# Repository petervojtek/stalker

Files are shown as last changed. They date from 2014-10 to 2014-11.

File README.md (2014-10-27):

Stalker
=======

_"The Zone wants to be respected. Otherwise it will punish."_ &mdash;  [ Stalker, 1979](http://en.wikipedia.org/wiki/Stalker_(1979_film))

Arduino&ndash;based door stalking device.

```
2014-10-03 11:30 door status changed to OPEN 
2014-10-03 11:32 door status changed to CLOSED
```

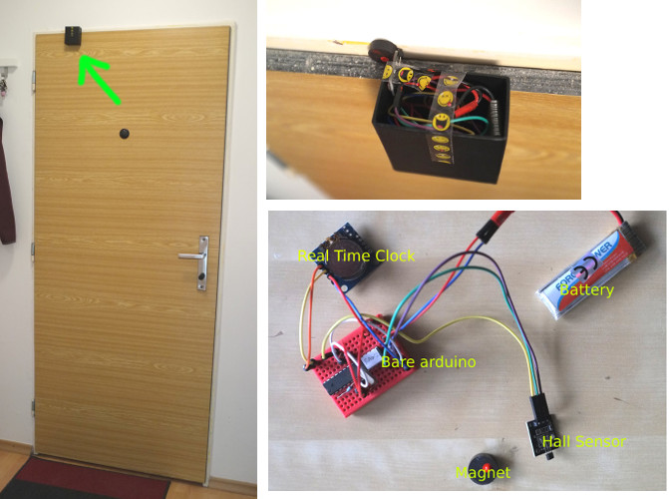
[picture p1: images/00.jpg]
Stalker


Features
--------

* Battery powered: will run for 3 months from `600mAh` lion battery.
* Cheap (20 USD): so that you can attach it to public-space door
* Hall sensor (magnet) based door status detection 
* Log entries are persistently stored to 32kB EEPROM on RTC board (6400 entries)

Wiring & Code
-------------

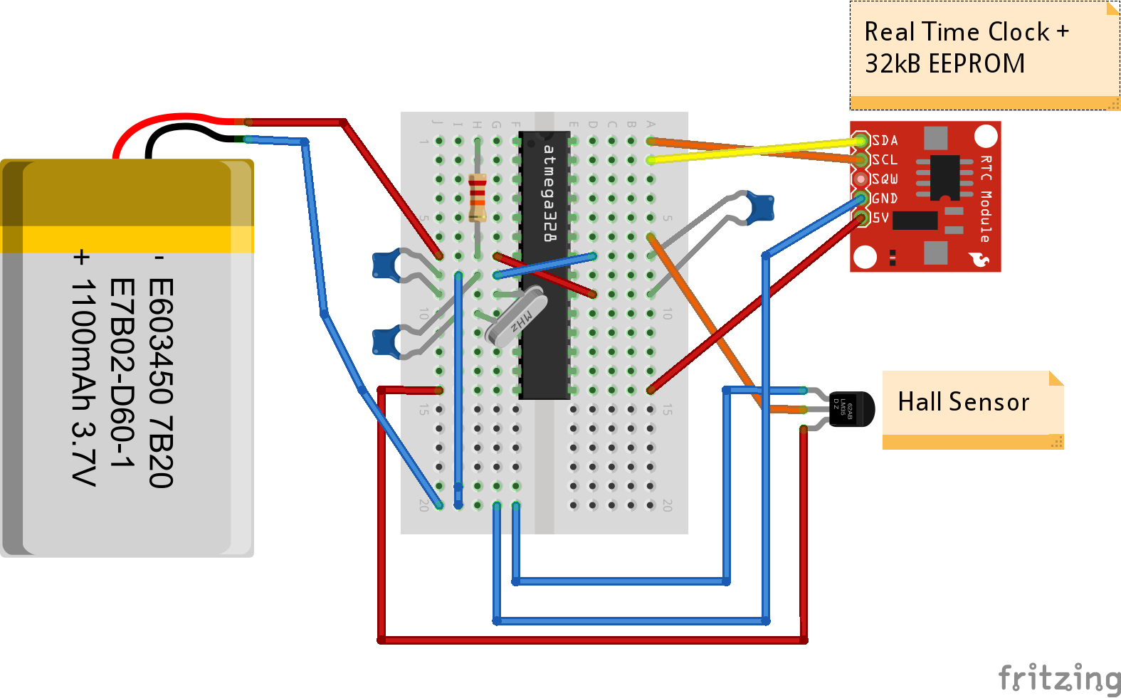
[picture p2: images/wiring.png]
Stalker fritzing diagram


Few notes on the [arduino source code](https://github.com/petervojtek/stalker/blob/master/stalker.ino):
* The circuit and source code is optimized to maximize battery life.
* Bare arduino is powered directly from lion battery without any voltage regulation. 
* Hall sensor is powered from arduino's digital pin (and not directly from battery) to cut its power consumption as much as possible. 
 * Similarly, real time clock is powered from arduino's digital pin for the same purpose.
* [LowPower.h](https://github.com/rocketscream/Low-Power) sleep mode is used as much as possible.
* Records are stored into A24C32 EEPROM (32kB), which is located on the RTC board.
* Use `printHistory()` function to get door logs from EEPROM.

Assembly
--------

You have to attach the Stalker and magnet on a door so that:
* the magnet is near the hall sensor when door is closed
* distance between magnet and hall sensor increase as door opens

The [KY-003 Hall sensor](http://www.ebay.com/itm/KY-003-Hall-Magnetic-Sensor-Module-for-Arduino-AVR-PIC-Good-/370886143225) has a LED which blinks when magnet is near, which is useful for tuning the hall sensor-to-magnet position.

Battery Life
------------

* If you want to achieve good battery life (months), you cannot use regular arduino which is too greedy in terms of current consumption. Instead [use bare atmega328 chip with arduino bootloader](https://github.com/petervojtek/diy/wiki/Arduino-with-Very-Low-Power-Consumption).
* Current draw is `0.20mA` when Stalker is on low-power sleep. 
* Every 2 seconds there is higher power demand as the hall sensor wakes up for 15 milliseconds and measures door status.
 * Only when hall sensor detects door status change, real time clock circuit is powered on and current time is fetched.
* I assume the average current draw is not more than `0.25mA` (unfortunately it is not possible to measure the current draw peaks properly with simple multimeter).
* `600mAh battery / 0.25 mA = 2400 hours = 100 days`

Bill of Material
----------------

Prices below include shipping to EU.

* [Atmega328 bare Arduino Uno Kit](http://www.ebay.de/itm/ATMEGA328-PU-ARDUINO-UNO-KIT-mit-5V-Spannungsstabilisator-MCU-A449-/261357577770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): 7.3 Euro
 * [mini breadboard](http://www.ebay.com/itm/Mini-Nickel-Plating-Breadboard-170-Tie-points-for-Arduino-Shield-Black-TN2F-/281265100067): 0.7 Euro
 * few wires 
* [KY-003 Hall sensor](http://www.ebay.com/itm/KY-003-Hall-Magnetic-Sensor-Module-for-Arduino-AVR-PIC-Good-/370886143225): 1.74 Euro
* [I2C Real Time Clock](http://www.ebay.com/itm/Arduino-I2C-RTC-DS1307-AT24C32-Real-Time-Clock-Module-For-AVR-ARM-PIC-SMD-/170910326110): 0.88 Euro
 * [CR2302 battery](http://www.ebay.com/itm/5-x-CR2032-DL2032-ECR2032-5004LC-3-Volt-Button-Cell-Battery-SL-/291197049625) ~ 0.2 Euro
* [600mAh lion battery](http://www.ebay.ca/itm/3-7V-600mAh-Lipo-Battery-for-Walkera-Syma-WLtoys-V929-V949-V959-V212-V222-/380960159510): 4.8 Euro
* Magnet
* Enclosure

Sum: 15.6 Euro (~ 19.52 USD)

TODOs
-----

* Add bluetooth module to wireless export door status records into a nearby cellphone.
* The current data format used to log door record into EEPROM is not effective - one log entry occupies 5 bytes, can be optimized to 3 bytes.
* There is no EEPROM memory overflow safety.

If you would like to contribute to Stalker's source code, you are welcome to share your enhancements via pull request.

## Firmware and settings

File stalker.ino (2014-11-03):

#include <EEPROM.h>
#include <lowpower.h>

// set to true to debug and see history of door open/close logs
// set to false in production mode
#define WITH_SERIAL_OUTPUT false 

// RTC parts of code are based on http://www.instructables.com/id/Setting-the-DS1307-Real-Time-Clock-using-the-Seria/
// which means this source code is licensed under Attribution-NonCommercial-ShareAlike

#include <Wire.h>
#define RTC_DIGITAL_POWER_PIN 9 // we turn off the rtc board between measurements to save battery
const int DS1307 = 0x68; // i2c Address of DS1307 from data sheets
const int EEPROM_AT24C32 = 0x50; // i2c address of 32kB eeprom, located on the same rtc board

byte second = 0;
byte minute = 0;
byte hour = 0;
byte weekday = 0;
byte monthday = 0;
byte month = 0;
byte year = 14; // fixed, we do not expect to run more than one year from battery

// door status
#define HALL_SENSOR_ANALOG_READ_PIN 0 
#define DOOR_OPEN 0
#define DOOR_CLOSED 1
#define HALL_SENSOR_DIGITAL_POWER_PIN 8 // we turn off the hall sensor between measurements to save battery

boolean doorStatusHasChanged = false;
int previousDoorStatus = DOOR_CLOSED;
int currentDoorStatus = DOOR_CLOSED;

void setup() {
  pinMode(HALL_SENSOR_DIGITAL_POWER_PIN, OUTPUT); 
  digitalWrite(HALL_SENSOR_DIGITAL_POWER_PIN, LOW);

  pinMode(RTC_DIGITAL_POWER_PIN, OUTPUT); 
  digitalWrite(RTC_DIGITAL_POWER_PIN, LOW); 

  Wire.begin();
  
  // load number of currently stored door records so that we can continue seamlessly
  loadRecordCounter(); 
  
  if(WITH_SERIAL_OUTPUT){
    Serial.begin(9600);
    delay(1000);
    Serial.println("printing history");
    printHistory();
    delay(1000);
    Serial.println("starting");
  } 
  else {
    delay(1000);
  }
  
  // uncomment the next line to clear the eeprom
  //resetRecordCounter();
}

void loop() {
  LowPower.powerDown(SLEEP_2S, ADC_OFF, BOD_OFF); // check door status every 2 seconds
  doorStatusHasChanged = updateDoorStatus();
  if(doorStatusHasChanged){
    powerOnRTC();
    
    readTime();
    printTime();
    printCurrentDoorStatus();
    storeDoorStatusToEeprom();
    
    powerOffRTC();
  }
}

void printCurrentDoorStatus(){
  if(WITH_SERIAL_OUTPUT){
    if(currentDoorStatus == DOOR_OPEN){
      Serial.println("door status changed to OPEN");
    } 
    else {
      Serial.println("door status changed to CLOSED");
    }
  }
}

long hallValue;

boolean updateDoorStatus(){
  previousDoorStatus = currentDoorStatus;

  digitalWrite(HALL_SENSOR_DIGITAL_POWER_PIN, HIGH);
  LowPower.powerDown(SLEEP_15Ms, ADC_OFF, BOD_OFF);  
  long hallValue = analogRead(HALL_SENSOR_ANALOG_READ_PIN);
  digitalWrite(HALL_SENSOR_DIGITAL_POWER_PIN, LOW);

  if(hallValue > 100){
    currentDoorStatus = DOOR_OPEN;
  } 
  else {
    currentDoorStatus = DOOR_CLOSED;
  }

  return(previousDoorStatus != currentDoorStatus);
}

byte decToBcd(byte val) {
  return ((val/10*16) + (val%10));
}
byte bcdToDec(byte val) {
  return ((val/16*10) + (val%16));
}


// if you want to calibrate current time of rtc board, call this function
// you will need to call this function when you replace the CR2032 battery
void setTime() {
  digitalWrite(RTC_DIGITAL_POWER_PIN, HIGH);
  LowPower.powerDown(SLEEP_15Ms, ADC_OFF, BOD_OFF);  

  year = 14; // 00-99
  month = 10; // 1-12
  monthday = 27; // 1-31
  weekday = 2; // 1 Sun | 2 Mon | 3 Tues | 4 Weds | 5 Thu | 6 Fri | 7 Sat
  hour = 20; // 0-23
  minute = 22; // 0-59
  second = 0;

  Wire.beginTransmission(DS1307);
  Wire.write(byte(0));
  Wire.write(decToBcd(second));
  Wire.write(decToBcd(minute));
  Wire.write(decToBcd(hour));
  Wire.write(decToBcd(weekday));
  Wire.write(decToBcd(monthday));
  Wire.write(decToBcd(month));
  Wire.write(decToBcd(year));
  Wire.write(byte(0));
  Wire.endTransmission();

  digitalWrite(RTC_DIGITAL_POWER_PIN, LOW);
}

void printTime() {
  if(WITH_SERIAL_OUTPUT){
    char buffer[3];
    Serial.print("20");
    Serial.print(year);
    Serial.print("-");
    sprintf(buffer, "%02d", month);
    Serial.print(buffer);
    Serial.print("-");
    sprintf(buffer, "%02d", monthday);
    Serial.print(buffer);
    Serial.print(" ");
    sprintf(buffer, "%02d", hour);
    Serial.print(buffer);
    Serial.print(":");
    sprintf(buffer, "%02d", minute);
    Serial.println(buffer);
  }
}

void readTime() {
  Wire.beginTransmission(DS1307);
  Wire.write(byte(0));
  Wire.endTransmission();
  Wire.requestFrom(DS1307, 7);
  second = bcdToDec(Wire.read());
  minute = bcdToDec(Wire.read());
  hour = bcdToDec(Wire.read());
  weekday = bcdToDec(Wire.read());
  monthday = bcdToDec(Wire.read());
  month = bcdToDec(Wire.read());
  year = bcdToDec(Wire.read());
  delay(10);
}


int recordCounter;
int eepromPointer;

void loadRecordCounter(){
  powerOnRTC();
  recordCounter = readEEPROM(0);
  powerOffRTC();
}

void resetRecordCounter(){
  powerOnRTC();
  writeEEPROM(0, 0);
  recordCounter = 0;
  powerOffRTC();
}

// one door record occupies 5 bytes. this can be reduced to 3 bytes if needed, but since we have 32kb eeprom, we have well enough space
void storeDoorStatusToEeprom(){
  eepromPointer = 1 + (recordCounter * 5);

  writeEEPROM(eepromPointer, month); 
  writeEEPROM(eepromPointer + 1, monthday);
  writeEEPROM(eepromPointer + 2, hour);
  writeEEPROM(eepromPointer + 3, minute);
  writeEEPROM(eepromPointer + 4, currentDoorStatus);

  recordCounter++;
  writeEEPROM(0, recordCounter);
}

void powerOnRTC(){
  digitalWrite(RTC_DIGITAL_POWER_PIN, HIGH);
  delay(10);
}

void powerOffRTC(){
  delay(10);
  digitalWrite(RTC_DIGITAL_POWER_PIN, LOW);
}

void printHistory(){
  powerOnRTC();
 
  Serial.println("history count:");
  Serial.println(recordCounter);
  for(int i = 0; i < recordCounter; i++){
    eepromPointer = 1 + (i * 5);
    month = readEEPROM(eepromPointer);
    monthday = readEEPROM(eepromPointer + 1);
    hour = readEEPROM(eepromPointer + 2);
    minute = readEEPROM(eepromPointer + 3);
    currentDoorStatus = readEEPROM(eepromPointer + 4);
    printTime();
    printCurrentDoorStatus();
    
  }
  powerOffRTC();
}


// parts of code below are from http://forum.arduino.cc/index.php?topic=211409.0
void writeEEPROM(unsigned int eeaddress, byte data ) 
{
  Wire.beginTransmission(EEPROM_AT24C32);
  Wire.write((int)(eeaddress >> 8));   // MSB
  Wire.write((int)(eeaddress & 0xFF)); // LSB
  Wire.write(data);
  Wire.endTransmission();
 
  delay(5);
}
 
byte readEEPROM(unsigned int eeaddress ) 
{
  byte rdata = 0xFF;
 
  Wire.beginTransmission(EEPROM_AT24C32);
  Wire.write((int)(eeaddress >> 8));   // MSB
  Wire.write((int)(eeaddress & 0xFF)); // LSB
  Wire.endTransmission();
 
  Wire.requestFrom(EEPROM_AT24C32,1);
 
  if (Wire.available()) rdata = Wire.read();
 
  return rdata;
}

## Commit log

2014-10-05 add Fritzing schema
    [stalker.fzz]
2014-10-27 update wiring to match new 32kb eeprom feature
    [stalker.fzz]
2014-11-03 add feature: do not reset the door record counter automatically after arduino reset
    [stalker.ino]
2014-11-03 fix bug: datetime is not properly aligned to %02d
    [stalker.ino]
